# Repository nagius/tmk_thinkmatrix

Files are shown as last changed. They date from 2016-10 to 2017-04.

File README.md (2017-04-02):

# ThinkMatrix Keyboard Firmware

This is the firmware for my custom ortholinear keyboard, based on the [tmk keyboard library](https://github.com/tmk/tmk_core).  

The keyboard runs on a [Teensy 2.0](http://www.pjrc.com/store/teensy.html). You can find more detail about the design of keyboard itself in the directory `docs`.

Images and a buildlog of the keyboard can be found [here](https://geekhack.org/index.php?topic=76167.0).

## Cloning, building & flashing

You need the AVR cross-compilation toolstack to compile the firmware.

See [tmk keyboard](https://github.com/tmk/tmk_keyboard) and [Teensy howto](https://www.pjrc.com/teensy/gcc.html) for more informations.

Since this repository has a submodule the cloning needs an additional argument to init and update the submodule.

```
git clone --recursive https://github.com/nagius/tmk_thinkmatrix
cd tmk_thinkmatrix
make
```

This will generate the firmware file `thinkmatrix-fw.hex`.

### Upload

Start the graphical [loader tool](https://www.pjrc.com/teensy/loader_linux.html) :

```
teensy.64bit &
```

Plug the Teensy on USB, push the program button, select the generated file `thinkmatrix-fw.hex` and click 'Upload'.

## Update to the lastest version

```
git pull
git submodule sync --recursive
git submodule update --init --recursive
```

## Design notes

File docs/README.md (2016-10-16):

# Documentation, schematics and drawing

You will find in this directory the files needed to buid the keyboard. Everything is released under GNU/GPLv3 Licence if not specified otherwise.
 
 - keyboard-layout.json: Data file for http://www.keyboard-layout-editor.com/
 - CAD: All LibreCAD needed to build the case and the plate
 - PCB: the KiCad project to make the PCB

Please note there is a couple of errors on this PCB design:

 - The pins labelling of the Teensy module are wrong, please refer to the table below for the correct pinout.
 - When soldering the Teensy, pins C6 and D7 must be swapped (with a couple of wire for example).
 - Clearance around the Cherry MX stabilizers is not good enough in few cases, 5 of the resistors need to be soldiered on the back of the board.
 - The diodes are in the wrong way around for the tmk_keyboard firmware, the matrix need to be rotated in the source code. Note this is tmk specific, it does not apply if you're using a qmk_keyboard firmware.

## Teensy pinout

 - Matrix

| Row | 0  | 1  | 2  | 3  | 4  | 5  | 6  |
|-----|----|----|----|----|----|----|----|
| Pin | B2 | B0 | B1 | E6 | B3 | B7 | D0 |

| Col | 0  | 1  | 2  | 3  | 4  | 5  | 6  | 7  | 8  | 9  | 10 | 11 | 12 | 13 |
|-----|----|----|----|----|----|----|----|----|----|----|----|----|----|----|
| Pin | F0 | F1 | F4 | B4 | F5 | D3 | D2 | C7 | F7 | B6 | B5 | D5 | D4 | C6 |

 - Front leds: D1, D6, F6
 - Backlight: D7

## Parts list

 - 1x  Teensy 2.0
 - 85x Cherry MX switches
 - 9x  Cherry MX stabilizers
 - 85x Diodes 1N4148
 - 89x Orange LEDs (1.92V @ 7mA)
 - 43x Resistors 36 ohms
 - 4x  Resistors 200 ohms
 - 1x  Resistor 1.4k ohms
 - 1x  Capacitor 100µF
 - 1x  Transistor 2N3904
 - 1x  Transistor PN2907A

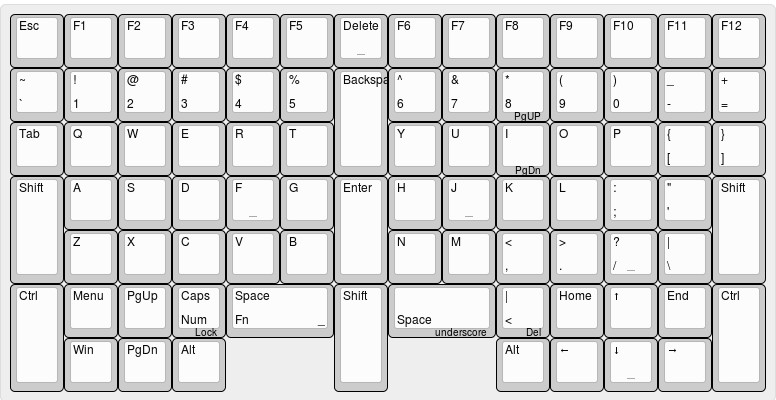
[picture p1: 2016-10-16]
docs/layout.jpg

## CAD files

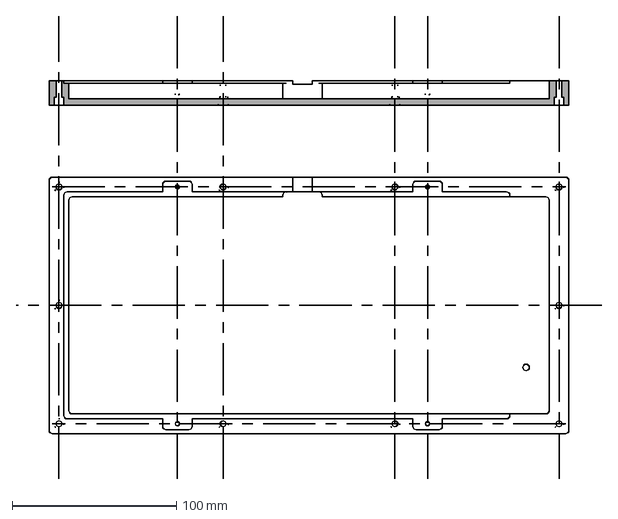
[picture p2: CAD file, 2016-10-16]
docs/CAD/CaseBottom_ThinkMatrix_v1.dxf
356.7 x 281.8 mm

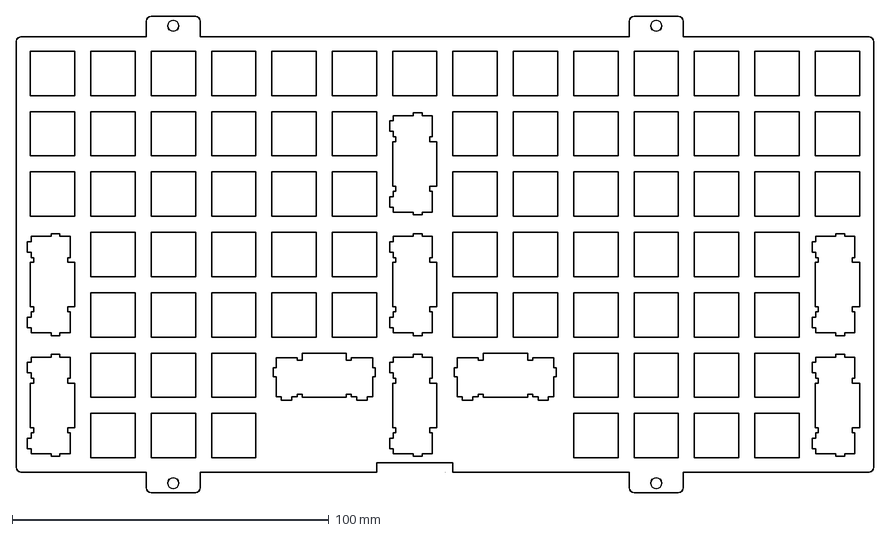
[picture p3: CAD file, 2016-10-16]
docs/CAD/Plate_ThinkMatrix_v1.dxf
270.7 x 150.3 mm

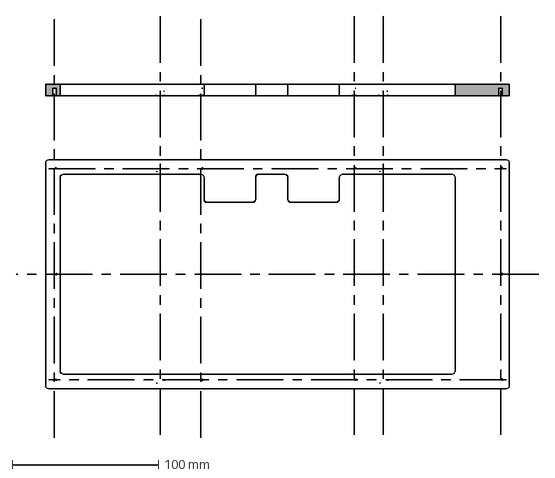
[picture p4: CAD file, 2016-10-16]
docs/CAD/CaseTop_ThinkMatrix_v1.dxf
356.7 x 287.8 mm

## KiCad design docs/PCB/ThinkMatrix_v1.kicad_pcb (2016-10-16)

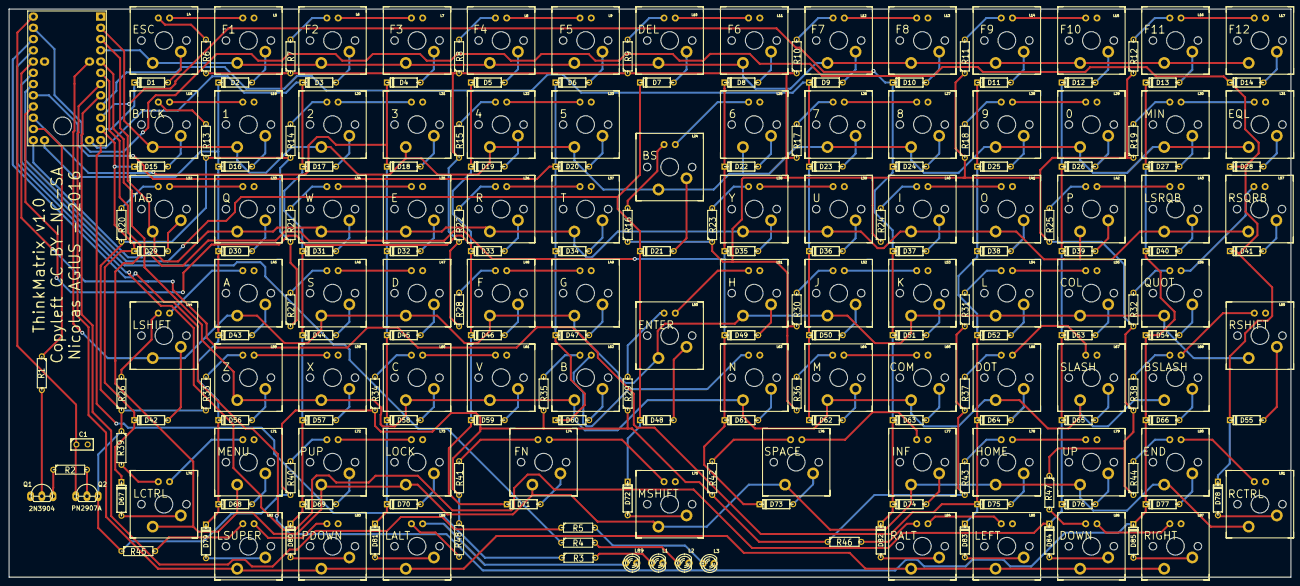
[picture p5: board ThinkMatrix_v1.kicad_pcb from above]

Board: 2 copper layers, 289.7 x 128.4 mm, 311 parts (0 on the bottom side), 205 nets.

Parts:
C1: 47µF; C1
D1, D2, D3, D4, D5, D6, D7, D8, D9, D10, D11, D12, D13, D14, D15, D16, D17, D18, D19, D20, D21, D22, D23, D24, D25, D26, D27, D28, D29, D30, D31, D32, D33, D34, D35, D36, D37, D38, D39, D40, D41, D42, D43, D44, D45, D46, D47, D48, D49, D50, D51, D52, D53, D54, D55, D56, D57, D58, D59, D60, D61, D62, D63, D64, D65, D66, D67, D68, D69, D70, D71, D72, D73, D74, D75, D76, D77, D78, D79, D80, D81, D82, D83, D84, D85: DIODE; D3
L1, L2, L3, L89: LED-3MM
L4: L4; MX1A-led-rev
L5: L5; MX1A-led-rev
L6: L6; MX1A-led-rev
L7: L7; MX1A-led-rev
L8: L8; MX1A-led-rev
L9: L9; MX1A-led-rev
L10: L10; MX1A-led-rev
L11: L11; MX1A-led-rev
L12: L12; MX1A-led-rev
L13: L13; MX1A-led-rev
L14: L14; MX1A-led-rev
L15: L15; MX1A-led-rev
L16: L16; MX1A-led-rev
L17: L17; MX1A-led-rev
L18: L18; MX1A-led-rev
L19: L19; MX1A-led-rev
L20: L20; MX1A-led-rev
L21: L21; MX1A-led-rev
L22: L22; MX1A-led-rev
L23: L23; MX1A-led-rev
L24: L24; MX1A-led-rev
L25: L25; MX1A-led-rev
L26: L26; MX1A-led-rev
L27: L27; MX1A-led-rev
L28: L28; MX1A-led-rev
L29: L29; MX1A-led-rev
L30: L30; MX1A-led-rev
L31: L31; MX1A-led-rev
L32: L32; MX1A-led-rev
L33: L33; MX1A-led-rev
L34: L34; MX1A-led-rev
L35: L35; MX1A-led-rev
L36: L36; MX1A-led-rev
L37: L37; MX1A-led-rev
L38: L38; MX1A-led-rev
L39: L39; MX1A-led-rev
L40: L40; MX1A-led-rev
L41: L41; MX1A-led-rev
L42: L42; MX1A-led-rev
L43: L43; MX1A-led-rev
L44: L44; MX1A-led-rev
L45: L45; MX1A-led-rev
L46: L46; MX1A-led-rev
L47: L47; MX1A-led-rev
L48: L48; MX1A-led-rev
L49: L49; MX1A-led-rev
L50: L50; MX1A-led-rev
L51: L51; MX1A-led-rev
L52: L52; MX1A-led-rev
L53: L53; MX1A-led-rev
L54: L54; MX1A-led-rev
L55: L55; MX1A-led-rev
L56: L56; MX1A-led-rev
L57: L57; MX1A-led-rev
L58: L58; MX1A-led-rev
L59: L59; MX1A-led-rev
L60: L60; MX1A-led-rev
L61: L61; MX1A-led-rev
L62: L62; MX1A-led-rev
L63: L63; MX1A-led-rev
L64: L64; MX1A-led-rev
L65: L65; MX1A-led-rev
L66: L66; MX1A-led-rev
L67: L67; MX1A-led-rev
L68: L68; MX1A-led-rev
L69: L69; MX1A-led-rev
L70: L70; MX1A-led-rev
L71: L71; MX1A-led-rev
L72: L72; MX1A-led-rev
L73: L73; MX1A-led-rev
L74: L74; MX1A-led-rev
L75: L75; MX1A-led-rev
L76: L76; MX1A-led-rev
L77: L77; MX1A-led-rev
L78: L78; MX1A-led-rev
L79: L79; MX1A-led-rev
L80: L80; MX1A-led-rev
L81: L81; MX1A-led-rev
L82: L82; MX1A-led-rev
L83: L83; MX1A-led-rev
L84: L84; MX1A-led-rev
L85: L85; MX1A-led-rev
L86: L86; MX1A-led-rev
L87: L87; MX1A-led-rev
L88: L88; MX1A-led-rev
Q1: 2N3904; LV_TO92-123_oval
Q2: PN2907A; LV_TO92-123_oval
R1: R1; R3
R2: R2; R3
R3: R3
R4: R4; R3
R5: R5; R3
R6: R6; R3
R7: R7; R3
R8: R8; R3
R9: R9; R3
R10: R10; R3
R11: R11; R3
R12: R12; R3
R13: R13; R3
R14: R14; R3
R15: R15; R3
R16: R16; R3
R17: R17; R3
R18: R18; R3
R19: R19; R3
R20: R20; R3
R21: R21; R3
R22: R22; R3
R23: R23; R3
R24: R24; R3
R25: R25; R3
R26: R26; R3
R27: R27; R3
R28: R28; R3
R29: R29; R3
R30: R30; R3
R31: R31; R3
R32: R32; R3
R33: R33; R3
R34: R34; R3
R35: R35; R3
R36: R36; R3
R37: R37; R3
R38: R38; R3
R39: R39; R3
R40: R40; R3
R41: R41; R3
R42: R42; R3
R43: R43; R3
R44: R44; R3
R45: R45; R3
R46: R46; R3
R47: R47; R3
R48: R48; R3
SW0:0: ESC; SW_PCB_2PIN_NO
SW0:1: F1; SW_PCB_2PIN_NO
SW0:2: F2; SW_PCB_2PIN_NO
SW0:3: F3; SW_PCB_2PIN_NO
SW0:4: F4; SW_PCB_2PIN_NO
SW0:5: F5; SW_PCB_2PIN_NO
SW0:6: DEL; SW_PCB_2PIN_NO
SW0:7: F6; SW_PCB_2PIN_NO
SW0:8: F7; SW_PCB_2PIN_NO
SW0:9: F8; SW_PCB_2PIN_NO
SW0:10: F9; SW_PCB_2PIN_NO
SW0:11: F10; SW_PCB_2PIN_NO
SW0:12: F11; SW_PCB_2PIN_NO
SW0:13: F12; SW_PCB_2PIN_NO
SW1:0: BTICK; SW_PCB_2PIN_NO
SW1:1: 1; SW_PCB_2PIN_NO
SW1:2: 2; SW_PCB_2PIN_NO
SW1:3: 3; SW_PCB_2PIN_NO
SW1:4: 4; SW_PCB_2PIN_NO
SW1:5: 5; SW_PCB_2PIN_NO
SW1:6: BS; SW_PCB_2PIN_NO
SW1:7: 6; SW_PCB_2PIN_NO
SW1:8: 7; SW_PCB_2PIN_NO
SW1:9: 8; SW_PCB_2PIN_NO
SW1:10: 9; SW_PCB_2PIN_NO
SW1:11: 0; SW_PCB_2PIN_NO
SW1:12: MIN; SW_PCB_2PIN_NO
SW1:13: EQL; SW_PCB_2PIN_NO
SW2:0: TAB; SW_PCB_2PIN_NO
SW2:1: Q; SW_PCB_2PIN_NO
SW2:2: W; SW_PCB_2PIN_NO
SW2:3: E; SW_PCB_2PIN_NO
SW2:4: R; SW_PCB_2PIN_NO
SW2:5: T; SW_PCB_2PIN_NO
SW2:7: Y; SW_PCB_2PIN_NO
SW2:8: U; SW_PCB_2PIN_NO
SW2:9: I; SW_PCB_2PIN_NO
SW2:10: O; SW_PCB_2PIN_NO
SW2:11: P; SW_PCB_2PIN_NO
SW2:12: LSRQB; SW_PCB_2PIN_NO
SW2:13: RSQRB; SW_PCB_2PIN_NO
SW3:0: LSHIFT; SW_PCB_2PIN_NO
SW3:1: A; SW_PCB_2PIN_NO
SW3:2: S; SW_PCB_2PIN_NO
SW3:3: D; SW_PCB_2PIN_NO
SW3:4: F; SW_PCB_2PIN_NO
SW3:5: G; SW_PCB_2PIN_NO
SW3:6: ENTER; SW_PCB_2PIN_NO
SW3:7: H; SW_PCB_2PIN_NO
SW3:8: J; SW_PCB_2PIN_NO
SW3:9: K; SW_PCB_2PIN_NO
SW3:10: L; SW_PCB_2PIN_NO
SW3:11: COL; SW_PCB_2PIN_NO
SW3:12: QUOT; SW_PCB_2PIN_NO
SW3:13: RSHIFT; SW_PCB_2PIN_NO
SW4:1: Z; SW_PCB_2PIN_NO
SW4:2: X; SW_PCB_2PIN_NO
SW4:3: C; SW_PCB_2PIN_NO
SW4:4: V; SW_PCB_2PIN_NO
SW4:5: B; SW_PCB_2PIN_NO
SW4:7: N; SW_PCB_2PIN_NO
SW4:8: M; SW_PCB_2PIN_NO
SW4:9: COM; SW_PCB_2PIN_NO
SW4:10: DOT; SW_PCB_2PIN_NO
SW4:11: SLASH; SW_PCB_2PIN_NO
SW4:12: BSLASH; SW_PCB_2PIN_NO
SW5:0: LCTRL; SW_PCB_2PIN_NO
SW5:1: MENU; SW_PCB_2PIN_NO
SW5:2: PUP; SW_PCB_2PIN_NO
SW5:3: LOCK; SW_PCB_2PIN_NO
SW5:4: FN; SW_PCB_2PIN_NO
SW5:6: MSHIFT; SW_PCB_2PIN_NO
SW5:7: SPACE; SW_PCB_2PIN_NO
SW5:9: INF; SW_PCB_2PIN_NO
SW5:10: HOME; SW_PCB_2PIN_NO
SW5:11: UP; SW_PCB_2PIN_NO
SW5:12: END; SW_PCB_2PIN_NO
SW5:13: RCTRL; SW_PCB_2PIN_NO
SW6:1: LSUPER; SW_PCB_2PIN_NO
SW6:2: PDOWN; SW_PCB_2PIN_NO
SW6:3: LALT; SW_PCB_2PIN_NO
SW6:9: RALT; SW_PCB_2PIN_NO
SW6:10: LEFT; SW_PCB_2PIN_NO
SW6:11: DOWN; SW_PCB_2PIN_NO
SW6:12: RIGHT; SW_PCB_2PIN_NO
U1: TEENSY2.0; TEENSY_2.0_rev

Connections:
GND: C1.2, L1.2, L2.2, L3.2, L5.2, L7.2, L9.2, L11.2, L13.2, L15.2, L17.2, L19.2, L21.2, L23.2, L25.2, L27.2, L29.2, L31.2, L33.2, L35.2, L37.2, L39.2, L41.2, L43.2, L45.2, L47.2, L49.2, L51.2, L53.2, L55.2, L57.2, L59.2, L61.2, L63.2, L65.2, L67.2, L69.2, L71.2, L73.2, L75.2, L77.2, L79.2, L81.2, L83.2, L85.2, L87.2, L89.2, Q1.1, U1.1
unnamed: L34.1, R21.2
unnamed: L36.1, R22.2
unnamed: L36.2, L37.1
unnamed: L34.2, L35.1
unnamed: L32.2, L33.1
unnamed: L32.1, R20.2
unnamed: L38.1, R23.2
unnamed: L40.1, R24.2
unnamed: L40.2, L41.1
unnamed: L38.2, L39.1
unnamed: L28.1, R18.2
unnamed: L28.2, L29.1
unnamed: L26.2, L27.1
unnamed: L26.1, R17.2
unnamed: L24.2, L25.1
unnamed: L24.1, R16.2
unnamed: L30.2, L31.1
unnamed: L30.1, R19.2
unnamed: L52.1, R30.2
unnamed: L54.1, R31.2
unnamed: L52.2, L53.1
unnamed: L54.2, L55.1
unnamed: L50.2, L51.1
unnamed: L50.1, R29.2
unnamed: L56.2, L57.1
unnamed: L58.1, R33.2
unnamed: L58.2, L59.1
unnamed: L56.1, R32.2
unnamed: L44.2, L45.1
unnamed: L44.1, R26.2
unnamed: L46.2, L47.1
unnamed: L42.2, L43.1
unnamed: L42.1, R25.2
unnamed: L48.2, L49.1
unnamed: L48.1, R28.2
unnamed: L46.1, R27.2
unnamed: R1.1, U1.19
unnamed: Q1.3, R2.1
unnamed: Q2.2, R2.2
unnamed: Q1.2, R1.2
unnamed: L6.1, R7.2
unnamed: L6.2, L7.1
unnamed: R4.1, U1.24
unnamed: R5.1, U1.8
unnamed: R3.1, U1.12
unnamed: L4.2, L5.1
unnamed: L20.2, L21.1
unnamed: L18.2, L19.1
unnamed: L18.1, R13.2
unnamed: L20.1, R14.2
unnamed: L16.2, L17.1
unnamed: L16.1, R12.2
unnamed: L22.1, R15.2
unnamed: L22.2, L23.1
unnamed: L8.2, L9.1
unnamed: L10.2, L11.1
unnamed: L10.1, R9.2
unnamed: L8.1, R8.2
unnamed: L14.2, L15.1
unnamed: L14.1, R11.2
unnamed: L12.2, L13.1
unnamed: L12.1, R10.2
unnamed: SW2:0.1, SW2:1.1, SW2:2.1, SW2:3.1, SW2:4.1, SW2:5.1, SW2:7.1, SW2:8.1, SW2:9.1, SW2:10.1, SW2:11.1, SW2:12.1, SW2:13.1, U1.3
unnamed: D12.2, D26.2, D39.2, D53.2, D65.2, D76.2, D84.2, U1.26
unnamed: L68.1, R38.2
unnamed: L70.1, R39.2
unnamed: L70.2, L71.1
unnamed: L68.2, L69.1
unnamed: L66.2, L67.1
unnamed: L66.1, R37.2
unnamed: L72.2, L73.1
unnamed: L74.2, L75.1
unnamed: L74.1, R41.2
unnamed: L72.1, R40.2
unnamed: L62.1, R35.2
unnamed: L62.2, L63.1
unnamed: L60.2, L61.1
unnamed: L60.1, R34.2
unnamed: L64.2, L65.1
unnamed: L64.1, R36.2
unnamed: L86.1, R47.2
unnamed: L88.1, R48.2
unnamed: L86.2, L87.1
unnamed: L88.2, L89.1
unnamed: L84.2, L85.1
unnamed: L84.1, R46.2
unnamed: D1.2, D15.2, D29.2, D42.2, D67.2, U1.11
unnamed: D6.2, D20.2, D34.2, D47.2, D60.2, U1.22
unnamed: D7.2, D21.2, D48.2, D72.2, U1.23
unnamed: L78.2, L79.1
unnamed: L78.1, R43.2
unnamed: L80.2, L81.1
unnamed: L76.2, L77.1
unnamed: L76.1, R42.2
unnamed: L82.2, L83.1
unnamed: L82.1, R45.2
unnamed: L4.1, R6.2
unnamed: L80.1, R44.2
unnamed: Q2.3, R6.1, R7.1, R8.1, R9.1, R10.1, R11.1, R12.1, R13.1, R14.1, R15.1, R16.1, R17.1, R18.1, R19.1, R20.1, R21.1, R22.1, R23.1, R24.1, R25.1, R26.1, R27.1, R28.1, R29.1, R30.1, R31.1, R32.1, R33.1, R34.1, R35.1, R36.1, R37.1, R38.1, R39.1, R40.1, R41.1, R42.1, R43.1, R44.1, R45.1, R46.1, R47.1, R48.1
unnamed: D46.1, SW3:4.2
unnamed: D33.1, SW2:4.2
unnamed: D5.2, D19.2, D33.2, D46.2, D59.2, D71.2, U1.21
unnamed: D19.1, SW1:4.2
unnamed: D4.1, SW0:3.2
unnamed: D71.1, SW5:4.2
unnamed: D59.1, SW4:4.2
unnamed: D4.2, D18.2, D32.2, D45.2, D58.2, D70.2, D81.2, U1.20
unnamed: D58.1, SW4:3.2
unnamed: D45.1, SW3:3.2
unnamed: D32.1, SW2:3.2
unnamed: D18.1, SW1:3.2
unnamed: D81.1, SW6:3.2
unnamed: D5.1, SW0:4.2
unnamed: D70.1, SW5:3.2
unnamed: D48.1, SW3:6.2
unnamed: D72.1, SW5:6.2
unnamed: D21.1, SW1:6.2
unnamed: D35.1, SW2:7.2
unnamed: D22.1, SW1:7.2
unnamed: D7.1, SW0:6.2
unnamed: D20.1, SW1:5.2
unnamed: D34.1, SW2:5.2
unnamed: D60.1, SW4:5.2
unnamed: D6.1, SW0:5.2
unnamed: D47.1, SW3:5.2
unnamed: D67.1, SW5:0.2
unnamed: D1.1, SW0:0.2
unnamed: SW1:0.1, SW1:1.1, SW1:2.1, SW1:3.1, SW1:4.1, SW1:5.1, SW1:6.1, SW1:7.1, SW1:8.1, SW1:9.1, SW1:10.1, SW1:11.1, SW1:12.1, SW1:13.1, U1.2
unnamed: D42.1, SW3:0.2
unnamed: D43.1, SW3:1.2
unnamed: D30.1, SW2:1.2
unnamed: D16.1, SW1:1.2
unnamed: D15.1, SW1:0.2
unnamed: D29.1, SW2:0.2
unnamed: C1.1, Q2.1, U1.29
unnamed: D3.2, D17.2, D31.2, D44.2, D57.2, D69.2, D80.2, U1.13
unnamed: D69.1, SW5:2.2
unnamed: D57.1, SW4:2.2
unnamed: D44.1, SW3:2.2
unnamed: D3.1, SW0:2.2
unnamed: D31.1, SW2:2.2
unnamed: D80.1, SW6:2.2
unnamed: D68.1, SW5:1.2
unnamed: D79.1, SW6:1.2
unnamed: D2.2, D16.2, D30.2, D43.2, D56.2, D68.2, D79.2, U1.17
unnamed: D56.1, SW4:1.2
unnamed: D17.1, SW1:2.2
unnamed: D2.1, SW0:1.2
unnamed: D27.1, SW1:12.2
unnamed: D40.1, SW2:12.2
unnamed: D12.1, SW0:11.2
unnamed: D66.1, SW4:12.2
unnamed: D77.1, SW5:12.2
unnamed: D54.1, SW3:12.2
unnamed: SW4:1.1, SW4:2.1, SW4:3.1, SW4:4.1, SW4:5.1, SW4:7.1, SW4:8.1, SW4:9.1, SW4:10.1, SW4:11.1, SW4:12.1, U1.5
unnamed: D53.1, SW3:11.2
unnamed: D65.1, SW4:11.2
unnamed: D39.1, SW2:11.2
unnamed: D26.1, SW1:11.2
unnamed: D76.1, SW5:11.2
unnamed: D84.1, SW6:11.2
unnamed: L1.1, R3.2
unnamed: L2.1, R4.2
unnamed: D14.1, SW0:13.2
unnamed: L3.1, R5.2
unnamed: D13.2, D27.2, D40.2, D54.2, D66.2, D77.2, D85.2, U1.27
unnamed: D28.1, SW1:13.2
unnamed: D14.2, D28.2, D41.2, D55.2, D78.2, U1.28
unnamed: D13.1, SW0:12.2
unnamed: D85.1, SW6:12.2
unnamed: D55.1, SW3:13.2
unnamed: D78.1, SW5:13.2
unnamed: D41.1, SW2:13.2
unnamed: D62.1, SW4:8.2
unnamed: D9.1, SW0:8.2
unnamed: D9.2, D23.2, D36.2, D50.2, D62.2, U1.9
unnamed: SW0:0.1, SW0:1.1, SW0:2.1, SW0:3.1, SW0:4.1, SW0:5.1, SW0:6.1, SW0:7.1, SW0:8.1, SW0:9.1, SW0:10.1, SW0:11.1, SW0:12.1, SW0:13.1, U1.4
unnamed: D50.1, SW3:8.2
unnamed: D51.1, SW3:9.2
unnamed: SW3:0.1, SW3:1.1, SW3:2.1, SW3:3.1, SW3:4.1, SW3:5.1, SW3:6.1, SW3:7.1, SW3:8.1, SW3:9.1, SW3:10.1, SW3:11.1, SW3:12.1, SW3:13.1, U1.31
unnamed: D37.1, SW2:9.2
unnamed: D24.1, SW1:9.2
unnamed: D73.1, SW5:7.2
unnamed: D8.2, D22.2, D35.2, D49.2, D61.2, D73.2, U1.18
unnamed: D61.1, SW4:7.2
unnamed: D49.1, SW3:7.2
unnamed: D23.1, SW1:8.2
unnamed: D36.1, SW2:8.2
unnamed: D8.1, SW0:7.2
unnamed: D75.1, SW5:10.2
unnamed: D64.1, SW4:10.2
unnamed: D11.2, D25.2, D38.2, D52.2, D64.2, D75.2, D83.2, U1.25
unnamed: D52.1, SW3:10.2
unnamed: D38.1, SW2:10.2
unnamed: D11.1, SW0:10.2
unnamed: D83.1, SW6:10.2
unnamed: SW5:0.1, SW5:1.1, SW5:2.1, SW5:3.1, SW5:4.1, SW5:6.1, SW5:7.1, SW5:9.1, SW5:10.1, SW5:11.1, SW5:12.1, SW5:13.1, U1.6
unnamed: D10.2, D24.2, D37.2, D51.2, D63.2, D74.2, D82.2, U1.10
unnamed: D82.1, SW6:9.2
unnamed: SW6:1.1, SW6:2.1, SW6:3.1, SW6:9.1, SW6:10.1, SW6:11.1, SW6:12.1, U1.7
unnamed: D74.1, SW5:9.2
unnamed: D63.1, SW4:9.2
unnamed: D25.1, SW1:10.2
unnamed: D10.1, SW0:9.2

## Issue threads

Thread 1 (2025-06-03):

Question bepo

Zorin95670, 2025-06-03:
Bonjour Marcel/nicolas,

je viens de voir votre post sur le forum bepo, et je serais tres intéressé par louer vos services, pour me faire mon clavier bepo personnalisé :)

Serait-il possible qu'on se contact pour en discuter :)

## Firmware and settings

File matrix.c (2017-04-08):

/*************************************************************************
 *
 * This file is part of tmk_thinkmatrix keyboard firmware.
 * Copyleft 2016 Nicolas Agius <nicolas.agius@lps-it.fr>
 * Original code Copyright 2012 Jun Wako <wakojun@gmail.com>
 *
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
 * ***********************************************************************/


#include <stdint.h>
#include <stdbool.h>
#include <avr/io.h>
#include <util/delay.h>
#include "print.h"
#include "debug.h"
#include "util.h"
#include "matrix.h"
#include "backlight.h"


static uint8_t debouncing = DEBOUNCE;

static matrix_row_t matrix[MATRIX_ROWS];
static matrix_row_t matrix_debouncing[MATRIX_ROWS];
static matrix_row_t read_cols(void);
static void unselect_rows(void);
static void select_row(uint8_t row);


inline
uint8_t matrix_rows(void)
{
	return MATRIX_ROWS;
}

inline
uint8_t matrix_cols(void)
{
	return MATRIX_COLS;
}


/* Column pin configuration
 * col: 0	1	2	3	4	5	6 
 * pin: B2	B0	B1	E6	B3	B7	D0
 */
static void  init_cols(void)
{
	// Input with pull-up(DDR:0, PORT:1)
	DDRB  &= ~( 1<<0 | 1<<1 | 1<<2 | 1<<3 | 1<<7 );
	PORTB |=  ( 1<<0 | 1<<1 | 1<<2 | 1<<3 | 1<<7 );

	DDRE  &= ~( 1<<6 );
	PORTE |=  ( 1<<6 );

	DDRD  &= ~( 1<<0 );
	PORTD |=  ( 1<<0 );
}


static matrix_row_t read_cols(void)
{
	return (PINB&(1<<2) ? 0 : (1<<0)) |
		   (PINB&(1<<0) ? 0 : (1<<1)) |
		   (PINB&(1<<1) ? 0 : (1<<2)) |
		   (PINE&(1<<6) ? 0 : (1<<3)) |
		   (PINB&(1<<3) ? 0 : (1<<4)) |
		   (PINB&(1<<7) ? 0 : (1<<5)) |
		   (PIND&(1<<0) ? 0 : (1<<6));
}

/* Row pin configuration
 * row: 0	1	2	3	4	5	6	7	8	9 	10	11	12	13
 * pin: F0	F1	F4	F3	D3	D2	F6	F7	D1	B5	B4	D5	D4	C6
 */
static void unselect_rows(void)
{
	// Hi-Z(DDR:0, PORT:0) to unselect
	DDRF  &= ~( 1<<0 | 1<<1 | 1<<4 | 1<<5 | 1<<6 | 1<<7 );
	PORTF &= ~( 1<<0 | 1<<1 | 1<<4 | 1<<5 | 1<<6 | 1<<7 );
	DDRD  &= ~( 1<<1 | 1<<2 | 1<<3 | 1<<4 | 1<<5 );
	PORTD &= ~( 1<<1 | 1<<2 | 1<<3 | 1<<4 | 1<<5 );
	DDRC  &= ~( 1<<6 );
	PORTC &= ~( 1<<6 );
	DDRB  &= ~( 1<<4 | 1<<5 );
	PORTB &= ~( 1<<4 | 1<<5 );
}

static void select_row(uint8_t row)
{
	// Output low(DDR:1, PORT:0) to select
	switch (row) {
		case 0:
			DDRF  |= (1<<0);
			PORTF &= ~(1<<0);
			break;
		case 1:
			DDRF  |= (1<<1);
			PORTF &= ~(1<<1);
			break;
		case 2:
			DDRF  |= (1<<4);
			PORTF &= ~(1<<4);
			break;
		case 3:
			DDRF  |= (1<<5);
			PORTF &= ~(1<<5);
			break;
		case 4:
			DDRD  |= (1<<3);
			PORTD &= ~(1<<3);
			break;
		case 5:
			DDRD  |= (1<<2);
			PORTD &= ~(1<<2);
			break;
		case 6:
			DDRF  |= (1<<6);
			PORTF &= ~(1<<6);
			break;
		case 7:
			DDRF  |= (1<<7);
			PORTF &= ~(1<<7);
			break;
		case 8:
			DDRD  |= (1<<1);
			PORTD &= ~(1<<1);
			break;
		case 9:
			DDRB  |= (1<<5);
			PORTB &= ~(1<<5);
			break;
		case 10:
			DDRB  |= (1<<4);
			PORTB &= ~(1<<4);
			break;
		case 11:
			DDRD  |= (1<<5);
			PORTD &= ~(1<<5);
			break;
		case 12:
			DDRD  |= (1<<4);
			PORTD &= ~(1<<4);
			break;
		case 13:
			DDRC  |= (1<<6);
			PORTC &= ~(1<<6);
			break;
	}
}

void matrix_init(void)
{
	// initialize rows
	unselect_rows();

	init_cols();
	init_leds();
	init_backlight();

	// initialize matrix state: all keys off
	for (uint8_t i=0; i < MATRIX_ROWS; i++) {
		matrix[i] = 0;
		matrix_debouncing[i] = 0;
	}
}

uint8_t matrix_scan(void)
{
	for (uint8_t i = 0; i < MATRIX_ROWS; i++) {
		select_row(i);
		_delay_us(30);	// without this wait read unstable value.
		matrix_row_t cols = read_cols();
		if (matrix_debouncing[i] != cols) {
			matrix_debouncing[i] = cols;
			if (debouncing) {
				debug("bounce!: "); debug_hex(debouncing); debug("\n");
			}
			debouncing = DEBOUNCE;
		}
		unselect_rows();
	}

	if (debouncing) {
		if (--debouncing) {
			_delay_ms(1);
		} else {
			for (uint8_t i = 0; i < MATRIX_ROWS; i++) {
				matrix[i] = matrix_debouncing[i];
			}
		}
	}

	return 1;
}

bool matrix_is_modified(void)
{
	if (debouncing) return false;
	return true;
}

inline
bool matrix_is_on(uint8_t row, uint8_t col)
{
	return (matrix[row] & ((matrix_row_t)1<<col));
}

inline
matrix_row_t matrix_get_row(uint8_t row)
{
	return matrix[row];
}

void matrix_print(void)
{
	print("\nr/c 01234567\n");
	for (uint8_t row = 0; row < matrix_rows(); row++) {
		phex(row); print(": ");
		pbin_reverse(matrix_get_row(row));
		print("\n");
	}
}

// vim: ts=4:sw=4:ai

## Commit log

2016-10-16 Added docs
    [CaseBottom_ThinkMatrix_v1.dxf, CaseTop_ThinkMatrix_v1.dxf, Plate_ThinkMatrix_v1.dxf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]
2017-04-08 Added PMW on front leds

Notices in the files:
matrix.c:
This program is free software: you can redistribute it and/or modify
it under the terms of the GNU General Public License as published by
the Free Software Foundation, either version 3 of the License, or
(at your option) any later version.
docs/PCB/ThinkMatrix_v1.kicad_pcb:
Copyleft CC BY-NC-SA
